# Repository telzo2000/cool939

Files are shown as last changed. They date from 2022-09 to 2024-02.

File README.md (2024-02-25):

# cool939

cool939 is keyboard.It is designed by m.ki.

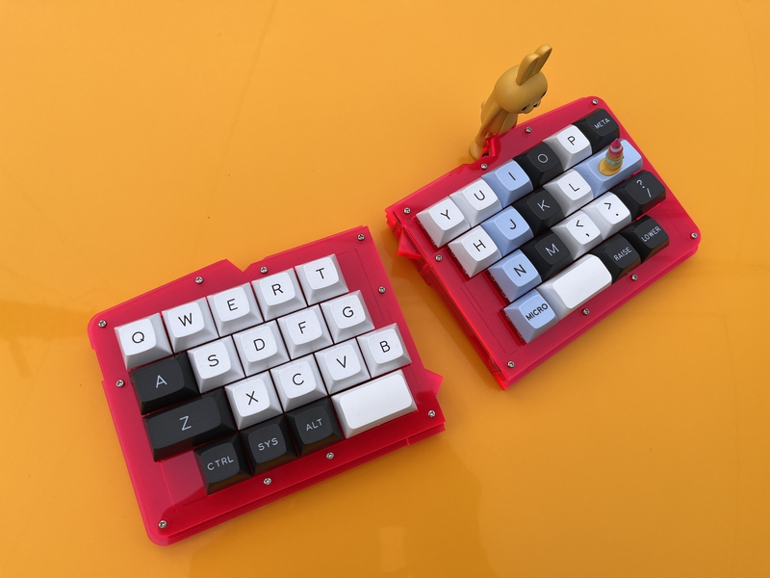
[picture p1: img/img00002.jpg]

## What is cool939?

cool939 is a split keyboard with a [qaz](https://www.cbkbd.com/product/qaz-keyboard-kit) layout.
<br>
[qaz](https://www.cbkbd.com/product/qaz-keyboard-kit)レイアウトの分割キーボードです。
<br>
<br>
And...
<br>
cool939 is the younger brother of cool936.
<br>
そして...
<br>
cool939はcool936の弟分です。
<br>

cool939
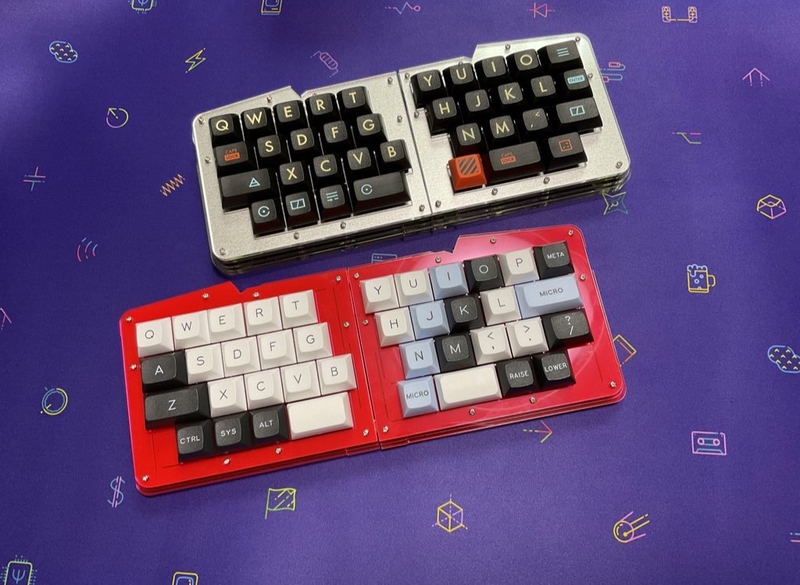
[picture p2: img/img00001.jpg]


cool939v2
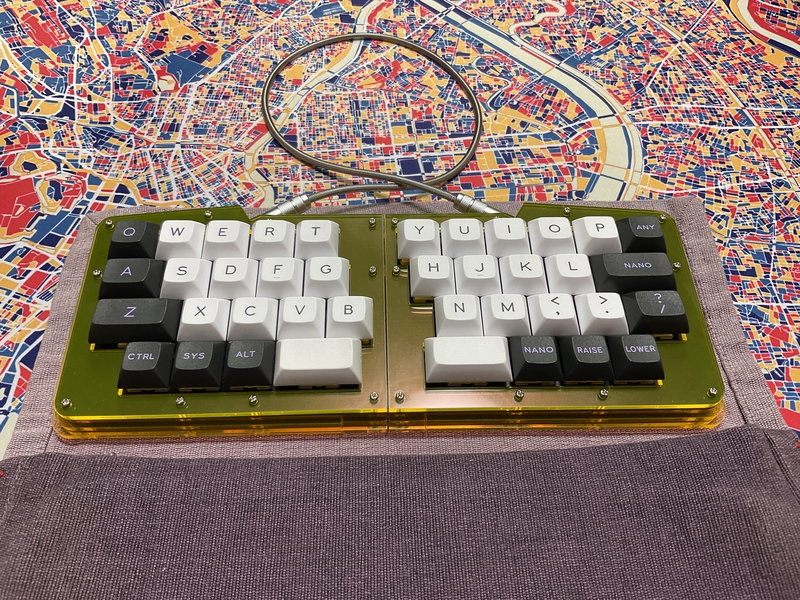
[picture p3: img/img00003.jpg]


The difference between cool939 and cool939v2 is the MCU and key layout.

<br>

## firmware

https://github.com/telzo2000/cool939/tree/main/firmware

## buildguide

Coming soon.
<br>
It is similar to cool936, so you can assemble it by referring to this build guide.
<br>
cool936 build guide

https://github.com/telzo2000/cool936/blob/main/buildguide_for_cool936.md

<br>

## parts list

|番号| 名前 | 数 | 備考 | 調達先の例 | 参考価格 |
|--|--|--|--|--|--|
|1|PCB Leftside|1|108.3 mm<br>* 86.8 mm|JLCPCB|５枚８ドル程度|
|2|PCB Rightside|1|114.3 mm<br>* 87.4 mm|↑|５枚で８ドル程度|
|3|Switch Plate|1|FR-4<br>左右一体で発注<br>256.7mm<br>* 99.3 mm|↑|５枚で25ドル程度|
|4|Top Plate|左右１枚ずつ|アクリル3mm|※１|※２|
|5|Middle Plate|３層分（15個に分割）|アクリル3mm|※１|※２|
|6|Bottom Plate|３層分|アクリル3mm|※１|※２|
|7|M2ネジ|32|15mm<br>TopPlate側から20本挿入<br>BottomPlate側（奥）から12本挿入|DIYショップ等|10本程度で100円|
|8|M2ネジ|8|６mm<br>BottomPlate側（手前）から挿入|DIYショップ等|10本程度で100円|
|9|M2スペーサー|20|８mm丸型※３|[ヒロスギネット](https://www.hirosugi-net.co.jp/shop/default.aspx)<br>[遊舎工房](https://shop.yushakobo.jp)等|20個で748円（税込）@ヒロスギネット|
|10|Diode|39本|リードタイプ、SMDのどちらでも可|[遊舎工房](https://shop.yushakobo.jp)<br>[TALP keyboard](https://talpkeyboard.net)|100個で220円（税込）|
|11|Reset Switch|2|タクタイルスイッチとも|[遊舎工房](https://shop.yushakobo.jp)<br>[TALP keyboard](https://talpkeyboard.net)|1個で11円（税込）|
|12|Switch Socket|39|Cherry MX互換|[遊舎工房](https://shop.yushakobo.jp)<br>[TALP keyboard](https://talpkeyboard.net)|10個で165円（税込）|
|13|TRRS Jack|2||[遊舎工房](https://shop.yushakobo.jp)<br>[TALP keyboard](https://talpkeyboard.net)等|１個55円（税込）|
|14a|Pro micro|cool939 PCB１枚につき１個|ピンヘッダが必要|[遊舎工房](https://shop.yushakobo.jp)<br>[TALP keyboard](https://talpkeyboard.net)|700〜1000円|
|14b|Pico micro|cool939v2　PCB１枚につき１個|ピンヘッダが必要|[AliExpress](https://ja.aliexpress.com/item/1005005980167753.html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,scm-url:1007.40050.354490.0,pvid:95b0a642-f35b-42d1-8a32-fa4f9e44a58d,tpp_buckets:668%232846%238111%231996&pdp_npi=4%40dis%21JPY%21515%21515%21%21%213.36%213.36%21%402101585c17088665968106079e786d%2112000035153406992%21rec%21JP%212171567483%21&utparam-url=scene%3ApcDetailTopMoreOtherSeller%7Cquery_from%3A)など|時価|
|15|キーキャップ|39|[DSS Micro](https://mechvault.net/products/dss-micro-keycap-set)推奨<br>※４|[遊舎工房](https://shop.yushakobo.jp)<br>[TALP keyboard](https://talpkeyboard.net)|1個で100円前後<br>キーキャップセットで3000円程度から|
|16|TRRSケーブル|１本||[遊舎工房](https://shop.yushakobo.jp)<br>[TALP keyboard](https://talpkeyboard.net)等|300円程度から|
|17|ゴム足|８|任意|DIYショップ等|100円程度|

※１　[工房merge+](https://www.emergeplus.jp/laser-cutting-service/contact/)、[遊舎工房](https://shop.yushakobo.jp/collections/services/products/lasercut)、[Elecrow](https://www.elecrow.com/acrylic-cutting.html) 等でアクリル加工が可能。
<br>
※２　The [case_wide folder](https://github.com/telzo2000/cool939/tree/main/case_wide) contains one 300mmX450mm acrylic file.
<br>
 [[case_wideフォルダ](https://github.com/telzo2000/cool939/tree/main/case_wide)には、300mmX450mmアクリル１枚にまとめられたファイルがある。
 <br>
※３　Due to the difference in acrylic accuracy, ８mm, which is slightly shorter than ９mm, is more suitable.
<br>アクリルの精度差により、９mmよりやや短い８mmの方が適当である。
<br>
※４　Since the cool939 is a QAZ-like keyboard, there are few keycaps to which the legend applies.
<br>
cool939は、QAZ的なキーボードなので、レジェンドが適応するキーキャップは少ない。

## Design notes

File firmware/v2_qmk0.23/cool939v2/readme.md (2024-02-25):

# cool939v2

cool939v2

*A short description of the keyboard/project*

* Keyboard Maintainer: [m.ki](https://github.com/telzo2000)
* Hardware Supported: *The PCBs, controllers supported*
* Hardware Availability: *Links to where you can find this hardware*

Make example for this keyboard (after setting up your build environment):

    make cool939v2:default

Flashing example for this keyboard:

    make cool939v2:default:flash

See the [build environment setup](https://docs.qmk.fm/#/getting_started_build_tools) and the [make instructions](https://docs.qmk.fm/#/getting_started_make_guide) for more information. Brand new to QMK? Start with our [Complete Newbs Guide](https://docs.qmk.fm/#/newbs).

## Bootloader

Enter the bootloader in 3 ways:

* **Bootmagic reset**: Hold down the key at (0,0) in the matrix (usually the top left key or Escape) and plug in the keyboard
* **Physical reset button**: Briefly press the button on the back of the PCB - some may have pads you must short instead
* **Keycode in layout**: Press the key mapped to `QK_BOOT` if it is available

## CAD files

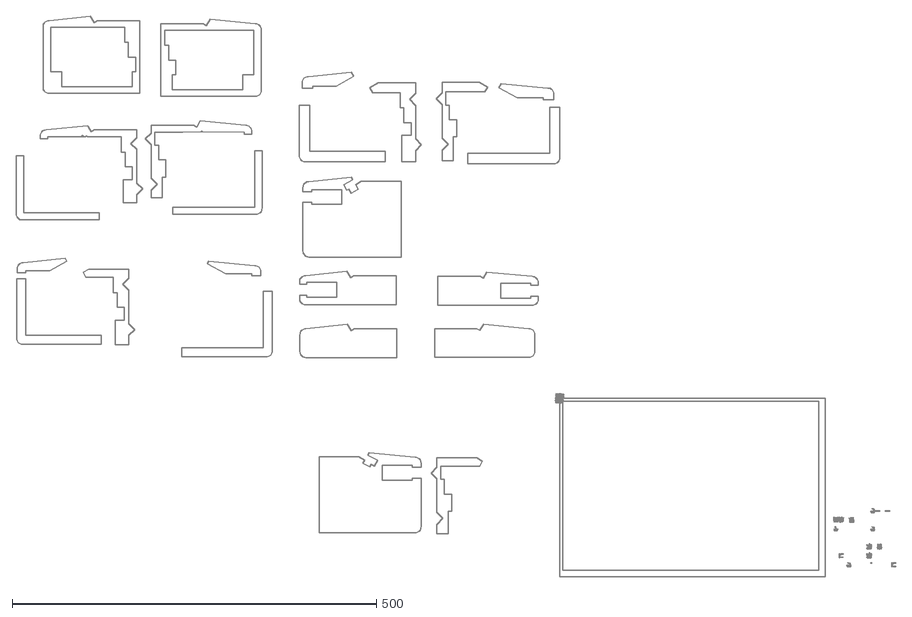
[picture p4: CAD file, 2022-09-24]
case_wide/case_wide/Laser_450x300_template_inkscape_cool939.dxf
1207.7 x 769.4

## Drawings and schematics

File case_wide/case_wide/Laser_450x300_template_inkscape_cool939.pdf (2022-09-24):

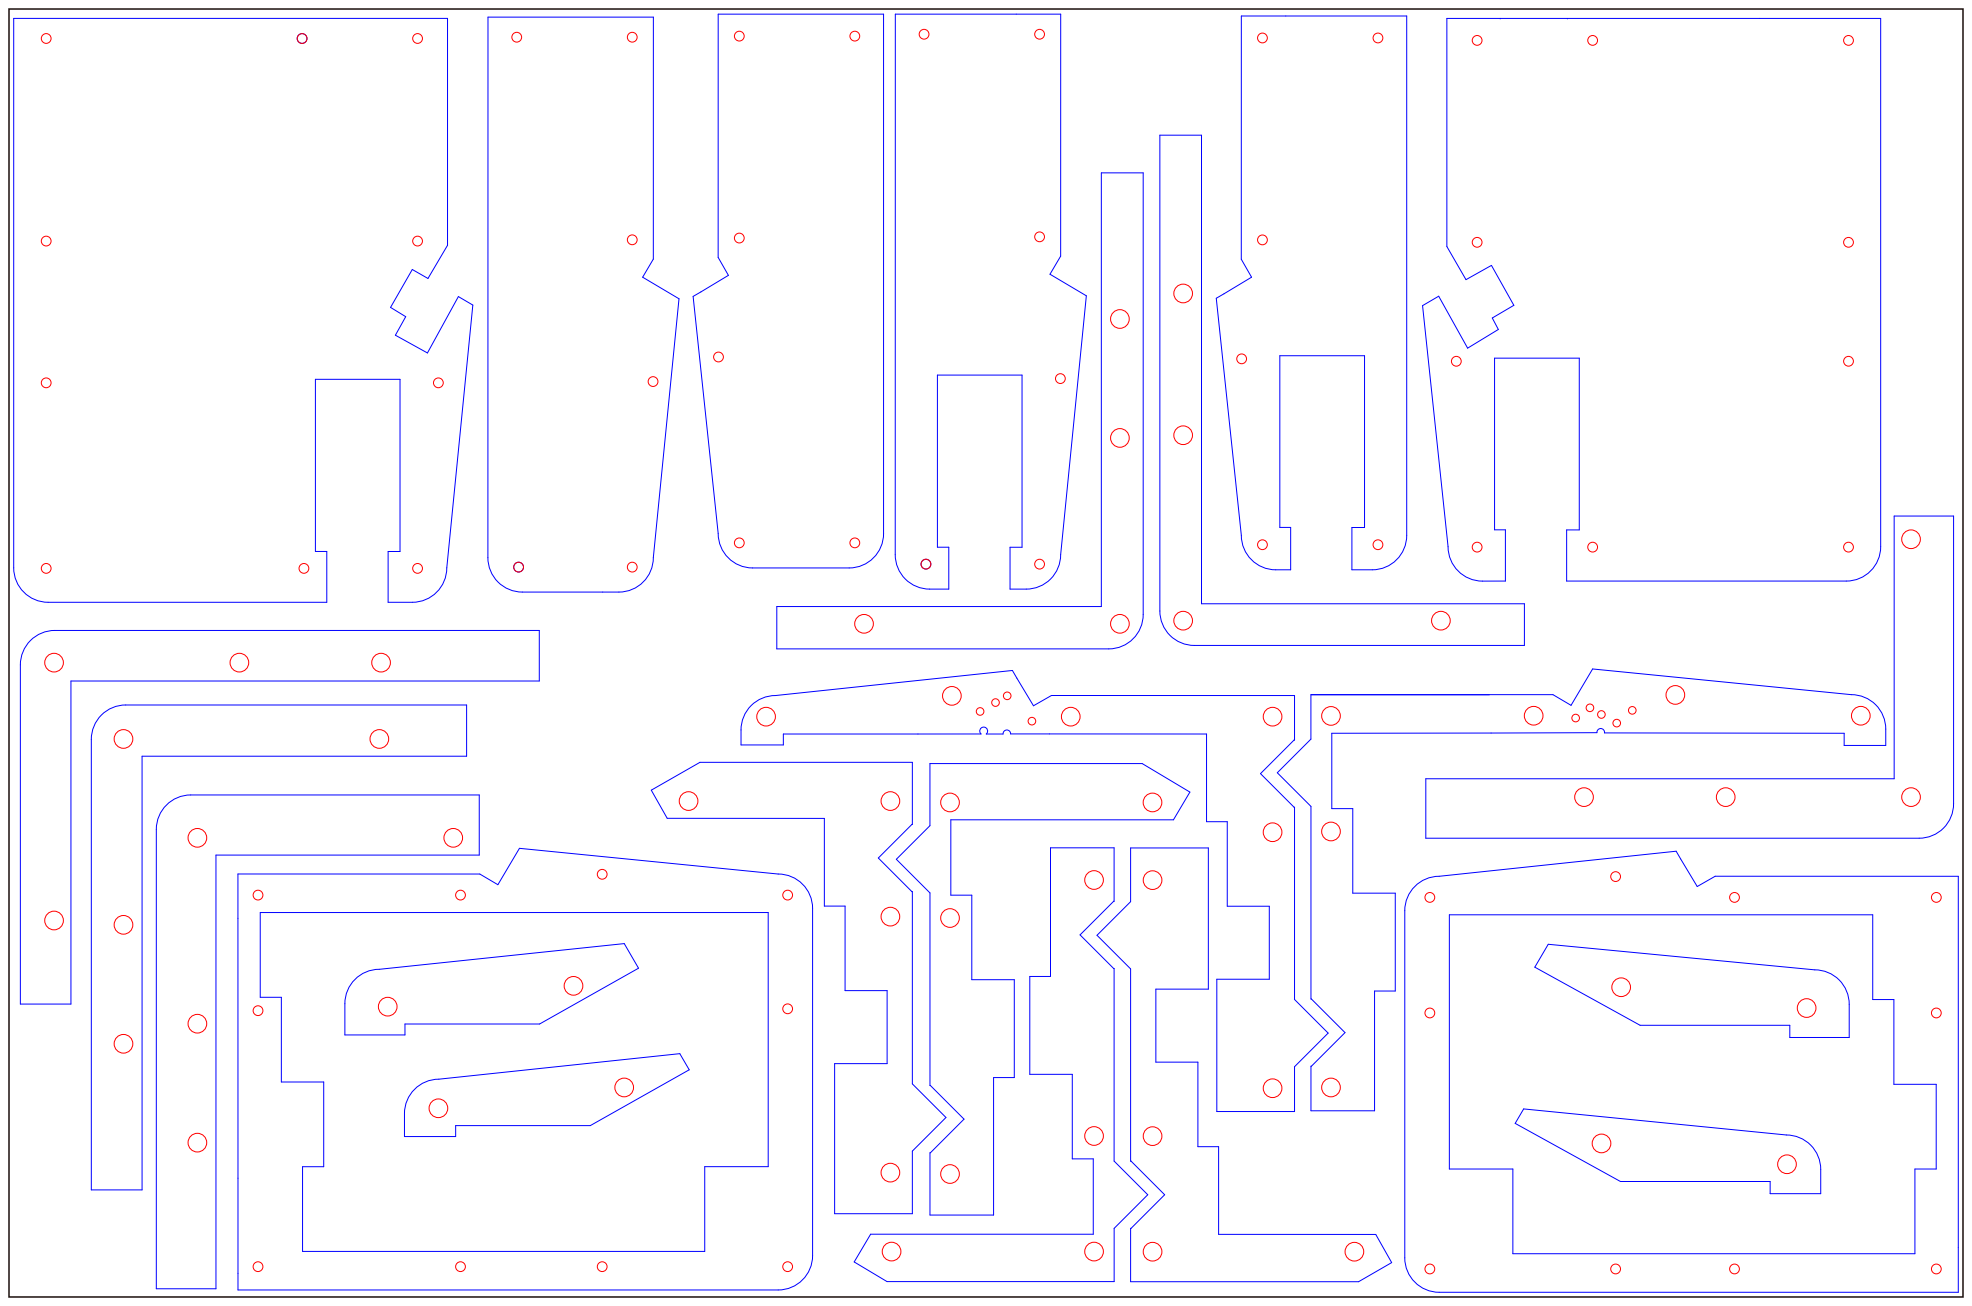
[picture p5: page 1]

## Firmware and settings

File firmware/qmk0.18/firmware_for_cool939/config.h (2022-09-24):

// Copyright 2022 m.ki (@telzo2000)
// SPDX-License-Identifier: GPL-2.0-or-later

#pragma once

#include "config_common.h"

/* USB Device descriptor parameter */
#define VENDOR_ID    0x4D43
#define PRODUCT_ID   0x0939
#define DEVICE_VER   0x0001
#define MANUFACTURER telzo2000
#define PRODUCT      cool939

/* key matrix size */
#define MATRIX_ROWS 8
#define MATRIX_COLS 5

/*
 * Keyboard Matrix Assignments
 *
 * Change this to how you wired your keyboard
 * COLS: AVR pins used for columns, left to right
 * ROWS: AVR pins used for rows, top to bottom
 * DIODE_DIRECTION: COL2ROW = COL = Anode (+), ROW = Cathode (-, marked on diode)
 *                  ROW2COL = ROW = Anode (+), COL = Cathode (-, marked on diode)
 *
 */
#define MATRIX_ROW_PINS { F6, F7, B3, B2 }
#define MATRIX_COL_PINS { D4, C6, D7, E6, B5 }
#define UNUSED_PINS

/* COL2ROW, ROW2COL */
#define DIODE_DIRECTION COL2ROW

/*
 * Split Keyboard specific options, make sure you have 'SPLIT_KEYBOARD = yes' in your rules.mk, and define SOFT_SERIAL_PIN.
 */
#define SOFT_SERIAL_PIN D2  // or D1, D2, D3, E6

//#define LED_NUM_LOCK_PIN B0
//#define LED_CAPS_LOCK_PIN B1
//#define LED_SCROLL_LOCK_PIN B2
//#define LED_COMPOSE_PIN B3
//#define LED_KANA_PIN B4

//#define BACKLIGHT_PIN B7
//#define BACKLIGHT_LEVELS 3
//#define BACKLIGHT_BREATHING

#define RGB_DI_PIN D3
#define RGBLIGHT_SPLIT
#define RGBLED_SPLIT { 6, 6 }
#ifdef RGB_DI_PIN
#    define RGBLED_NUM 16
#    define RGBLIGHT_HUE_STEP 16
#    define RGBLIGHT_SAT_STEP 16
#    define RGBLIGHT_VAL_STEP 16  
#    define RGBLIGHT_LIMIT_VAL 255 /* The maximum brightness level */
#    define RGBLIGHT_SLEEP  /* If defined, the RGB lighting will be switched off when the host goes to sleep */
/*== all animations enable ==*/
//#    define RGBLIGHT_ANIMATIONS
/*== or choose animations ==*/
#    define RGBLIGHT_EFFECT_BREATHING
#    define RGBLIGHT_EFFECT_RAINBOW_MOOD
#    define RGBLIGHT_EFFECT_RAINBOW_SWIRL
#    define RGBLIGHT_EFFECT_SNAKE
#    define RGBLIGHT_EFFECT_KNIGHT
#    define RGBLIGHT_EFFECT_CHRISTMAS
#    define RGBLIGHT_EFFECT_STATIC_GRADIENT
#    define RGBLIGHT_EFFECT_RGB_TEST
#    define RGBLIGHT_EFFECT_ALTERNATING
/*== customize breathing effect ==*/
/*==== (DEFAULT) use fixed table instead of exp() and sin() ====*/
#    define RGBLIGHT_BREATHE_TABLE_SIZE 256      // 256(default) or 128 or 64
/*==== use exp() and sin() ====*/
#    define RGBLIGHT_EFFECT_BREATHE_CENTER 1.85  // 1 to 2.7
#    define RGBLIGHT_EFFECT_BREATHE_MAX    255   // 0 to 255
#endif

/* Debounce reduces chatter (unintended double-presses) - set 0 if debouncing is not needed */
#define DEBOUNCE 5

/* define if matrix has ghost (lacks anti-ghosting diodes) */
//#define MATRIX_HAS_GHOST

/* Mechanical locking support. Use KC_LCAP, KC_LNUM or KC_LSCR instead in keymap */
#define LOCKING_SUPPORT_ENABLE
/* Locking resynchronize hack */
#define LOCKING_RESYNC_ENABLE

/* If defined, GRAVE_ESC will always act as ESC when CTRL is held.
 * This is useful for the Windows task manager shortcut (ctrl+shift+esc).
 */
//#define GRAVE_ESC_CTRL_OVERRIDE

/*
 * Force NKRO
 *
 * Force NKRO (nKey Rollover) to be enabled by default, regardless of the saved
 * state in the bootmagic EEPROM settings. (Note that NKRO must be enabled in the
 * makefile for this to work.)
 *
 * If forced on, NKRO can be disabled via magic key (default = LShift+RShift+N)
 * until the next keyboard reset.
 *
 * NKRO may prevent your keystrokes from being detected in the BIOS, but it is
 * fully operational during normal computer usage.
 *
 * For a less heavy-handed approach, enable NKRO via magic key (LShift+RShift+N)
 * or via bootmagic (hold SPACE+N while plugging in the keyboard). Once set by
 * bootmagic, NKRO mode will always be enabled until it is toggled again during a
 * power-up.
 *
 */
//#define FORCE_NKRO

/*
 * Feature disable options
 *  These options are also useful to firmware size reduction.
 */

/* disable debug print */
//#define NO_DEBUG

/* disable print */
//#define NO_PRINT

/* disable action features */
//#define NO_ACTION_LAYER
//#define NO_ACTION_TAPPING
//#define NO_ACTION_ONESHOT

/* disable these deprecated features by default */
#define NO_ACTION_MACRO
#define NO_ACTION_FUNCTION

/* Bootmagic Lite key configuration */
//#define BOOTMAGIC_LITE_ROW 0
//#define BOOTMAGIC_LITE_COLUMN 0
